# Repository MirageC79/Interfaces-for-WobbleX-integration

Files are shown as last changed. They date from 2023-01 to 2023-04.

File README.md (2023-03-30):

screen-gif
# Interfaces-for-WobbleX-integration

### Printers currently supported:
**Creality**
   - [Creality Ender 3](https://github.com/MirageC79/Interfaces-for-WobbleX-integration/tree/main/Creality/Ender3)

**RatRig**
   - [V-Core 3.1](https://github.com/MirageC79/Interfaces-for-WobbleX-integration/blob/main/RatRig/VCore3.1)  
   - V-Minion ........ *coming soon...*  

**Voron**
   - [Trident](https://github.com/MirageC79/Interfaces-for-WobbleX-integration/tree/main/Voron/Trident)  
   - V0 ............... *rear panel impacted, investigating feasibility and demand*  
<details><summary> Coming Soon: </summary>
<p>  

**VzBoT**
   - VZ235 ........... Currently not possible, clashing with RSCS ducting.
   - VZ330 ........... Currently not possible, clashing with RSCS ducting. 
</p>
</details>
<br>

**Mockups**
   - [Mockups for WobbleX custom installation](https://github.com/MirageC79/Interfaces-for-WobbleX-integration/tree/main/MockUp)
<br>

## What is WobbleX ?
The WobbleX isolators were born after spending a lot of efforts in creating a strong and reliable triple Z axis for self levelling with multi-axis printing provisions.
Because building a DIY 3D printer can induce a lot variability into the end result, we needed a way to limit the impact of:
- Components sources and origin
- Printed parts tolerances
- Assembly process
- User modifications 
- etc...

## How does it work?
This metallic version of the Wobble Rings from EvoMoto will compensate for screw wobbling AND nut tilting.  This 4 axis compensation ensures that the XY position of the bed will not be changed even if the screw is trying to.  It will also prevent the Z distance from being affected by a curved screw axis which would tilt the nut.

Each WobbleX Isolator is composed of an aluminum cross sandwiched between 4 Ball bearings and roller pins. The ball bearings will self center and retain themselves on the assembly using disc magnets.

One interface disc will allow the WobbleX to slide and pivot on the Screw Nut while the other interface disc will match the bed mount.  

## How can you integrate this on your printer?
In this repository you will find CADs and STLs that can be adapted to various 3D printers in order to benefit from the best Z wobble management system out there.

Buy WobbleX on Aliexpress Mellow 3D Official Store: https://s.click.aliexpress.com/e/_DDdeMyP

Preview of HevORT ZR2.6 Z axis integrating WS12 WobbleX:
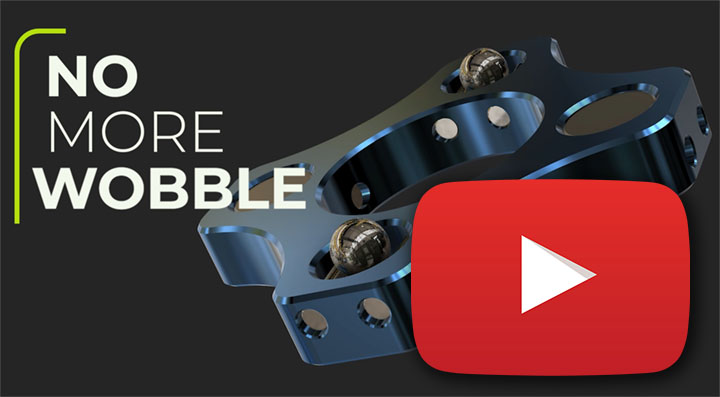
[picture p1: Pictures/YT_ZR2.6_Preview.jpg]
Video (https://www.youtube.com/watch?v=mLhklORNFBQ)


## Credits:
- EvoMoto for the awesome Idea
- Mellow 3D for materializing this idea
- HevORT Community for the support

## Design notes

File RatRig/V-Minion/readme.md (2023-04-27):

An Idea for the RatRig V-Minion based on the WobbleX concept. 

Improvement is in progress but it works pretty well so far.

It is not possible to order the WobbleX WS8 at my place so I designed something similar.

Additional to the printed parts I used:
* 16 pcs. steel pins 3x10 mm
* 4 pcs. 4 mm steel balls
* 8 pcs. 3x6 mm neodym magnets
* 2 pcs. M3x12 screws and nuts
* 1 pc. M3x6x5 threaded insert
* 1 pc. M3x10 screw

If you have the WobbleX WS8 you need less.

I printed everything in PLA with the steel pin side on the bed and 1mm brim. A pause has to be added in the slicer to insert the magnets.

At the V-Minion the lead screw should be aligned well with the coupler first, than replace the coupler with the WobbleX assembly.

WobbleXII_V-Minion

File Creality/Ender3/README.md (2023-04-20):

# Creality Ender 3

These parts will allow installation of WobbleX Isolators WS8 on Ender 3.  
## WARNING 
* Following user feedback, this system is not recommended for Dual Z cartesian printers.  The WobbleX require a certain amount of weight to keep them together.  A Dual Z installation would divide the XZ gantry weight.
* It is recommended that you use a T-Nut with limited amount of wear to avoid system twisting. Longer T-Nut with more threads is prefered.
* It is recommended that you use use a PTFE based lubricant or other friction reduction lubricants on you leadscrew.  

Notes:
* - I do not own a Creality Ender 3, these parts have not been physically validated.  See the [Feedback](/Creality/Ender3/README.md) section.
* - This mod will require that you relocate the stock Extruder.  Either go Direct Drive or create a bracket that will offset the extruder to make room for the WobbleX
* - Special care might be required to avoid nozzle bumping into blobs.  This might throw gantry up and separate the wobbleX.

## BOM
Bill of Material required to accomplish this modification:
|  Qty | Description | Link  |
|  :---:  |---|---|
|  1 | WobbleX WS8 kit for 8mm lead screw from Mellow 3D<br>Kit Includes:<br>  Qty8 - 3mm diam X 8mm longs pins<br>  Qty4 - 4mm ball screws<br>  Qty1 - WobbleX Assembly (Magnets and pins loaded)  | https://s.click.aliexpress.com/e/_DFcwPoH |
|  1 | 8mm T-Nut Adapter Lower Disc | [WobbleX_TR8_Adapter body.stl](https://github.com/MirageC79/Interfaces-for-WobbleX-integration/blob/main//Creality/Ender3/WobbleX_TR8_Adapter%20Body.stl)|
|  1 | Z carriage adapter | [ZCarriage_WS8.stl](https://github.com/MirageC79/Interfaces-for-WobbleX-integration/blob/main/Creality/Ender3/ZCarriage_WS8.stl)
|  1 | Top bearing mount (mandatory) | [TopBearingSupport_608.stl](https://github.com/MirageC79/Interfaces-for-WobbleX-integration/blob/main/Creality/Ender3/TopBearingSupport_608.stl)
|  1 | 608 Bearing |  AliExpress, Amazon, etc...
|  2 | M5X12 Button Head screws (for top bearing mount) | AliExpress, Amazon, etc...
|  5 | M3X8 Screws (3 for Z carriage Adapter +2 for lower disc) | AliExpress, Amazon, etc...
|  2 | 2020 M5 TNuts (for top bearing mount) | AliExpress, Amazon, etc...

## STEP files:  
[GitHub Directory](https://github.com/MirageC79/Interfaces-for-WobbleX-integration/tree/main/Creality/Ender3)
<br> 
<br>

## Feedback
I hope you enjoy this modification as much as I do.  As I dont have have an Ender 3 myself, I did not validate this installation physically. 
May you have any issue with the installation please [log an issue.](https://github.com/MirageC79/Interfaces-for-WobbleX-integration/issues)

Happy Printing :smiley:

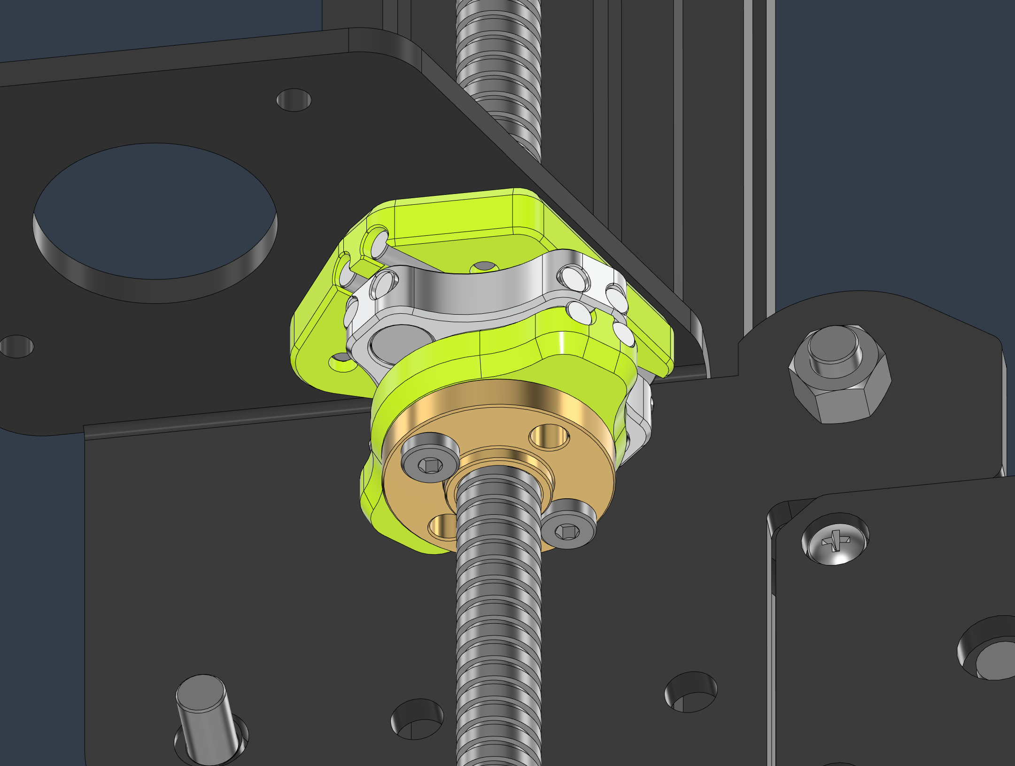
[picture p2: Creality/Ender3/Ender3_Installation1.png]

<br>
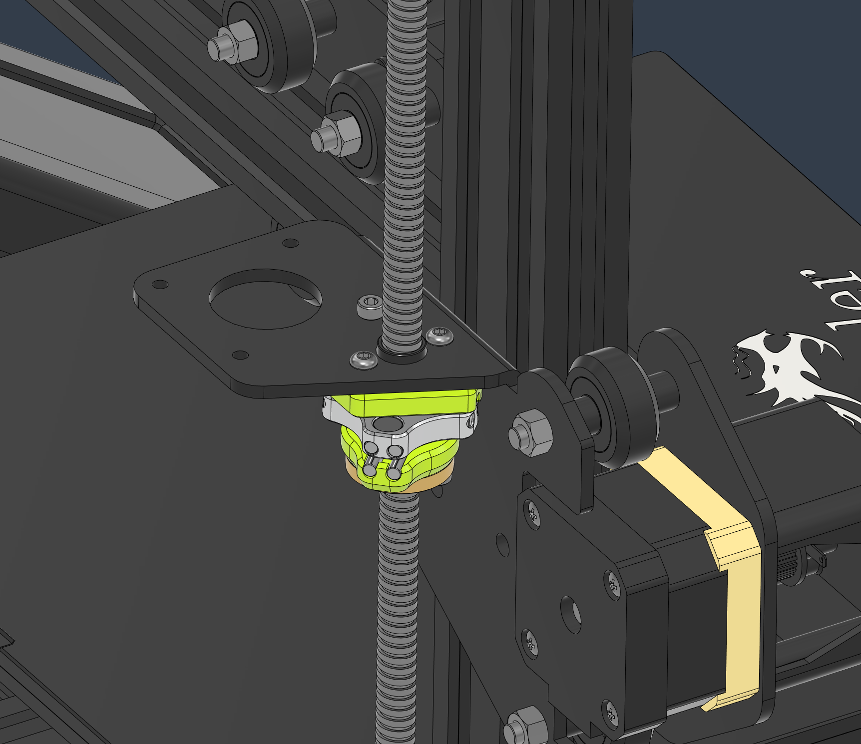
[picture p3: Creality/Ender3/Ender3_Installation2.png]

<br>
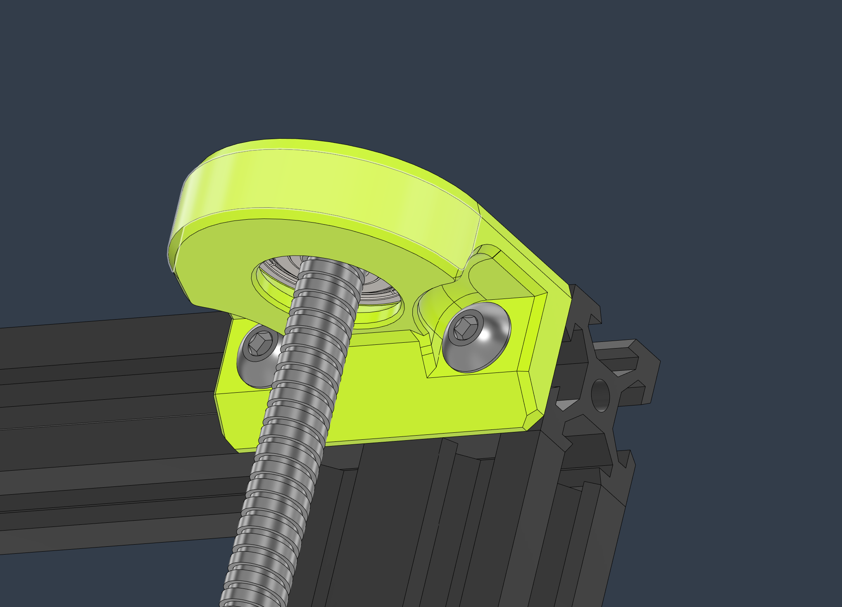
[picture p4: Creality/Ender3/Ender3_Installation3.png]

<br>
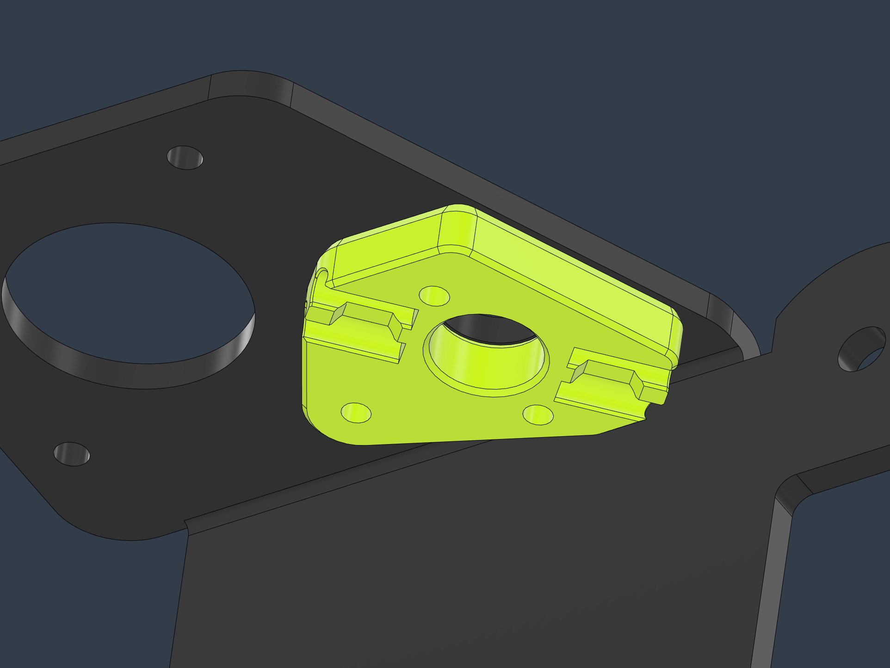
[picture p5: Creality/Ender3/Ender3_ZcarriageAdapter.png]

<br>

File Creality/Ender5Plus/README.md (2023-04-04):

Documentation is in work...

Creality Ender 5 Plus

Designed to reuse original hardware

Lead Screw support (TopBearingSupport_608.stl) is obtained from
https://www.thingiverse.com/thing:4808568
By mejico
https://www.thingiverse.com/mejico/designs

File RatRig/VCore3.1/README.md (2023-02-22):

# RatRig V-Core 3.1

These parts will allow installation of WobbleX Isolators WS8 on RatRig V-Core 3.1.  

Notes:
* - I do not own a RatRig V-Core, these parts have not been physically validated.  See the [Feedback](/RatRig/VCore3.1/README.md) section.

## BOM
Bill of Material required to accomplish this modification:
|  Qty | Description | Link  |
|  :---:  |---|---|
|  3 | WobbleX WS8 kit for 8mm lead screw from Mellow 3D | https://s.click.aliexpress.com/e/_DFcwPoH |
|  3 | 8mm T-Nut Adapter Lower Disc | [WobbleX_TR8_Adapter v6.stl](https://github.com/MirageC79/Interfaces-for-WobbleX-integration/blob/main/RatRig/VCore3.1/WobbleX_TR8_Adapter%20Body.stl)|
|  1 | Bed Arm left | [BedArmLeft_3.1_WS8.stl](https://github.com/MirageC79/Interfaces-for-WobbleX-integration/blob/main/RatRig/VCore3.1/BedArmLeft_3.1_WS8.stl)|
|  1 | Bed Arm Right | [BedArmRight_3.1_WS8.stl](https://github.com/MirageC79/Interfaces-for-WobbleX-integration/blob/main/RatRig/VCore3.1/BedArmRight_3.1_WS8.stl)|
|  1 | Bed Arm Back | [BedArmBack_3.1_WS8.stl](https://github.com/MirageC79/Interfaces-for-WobbleX-integration/blob/main/RatRig/VCore3.1/BedArmBack_3.1_WS8.stl)|

## STEP files:  
[GitHub Directory](https://github.com/MirageC79/Interfaces-for-WobbleX-integration/tree/main/RatRig/VCore3.1)
<br> 
<br>

## Feedback
I hope you enjoy this modification as much as I do.  As I dont have have a Trident myself, I did not validate this installation physically. 
May you have any issue with the installation please [log an issue.](https://github.com/MirageC79/Interfaces-for-WobbleX-integration/issues)

Happy Printing :smiley:
<br><br>

## Gallery
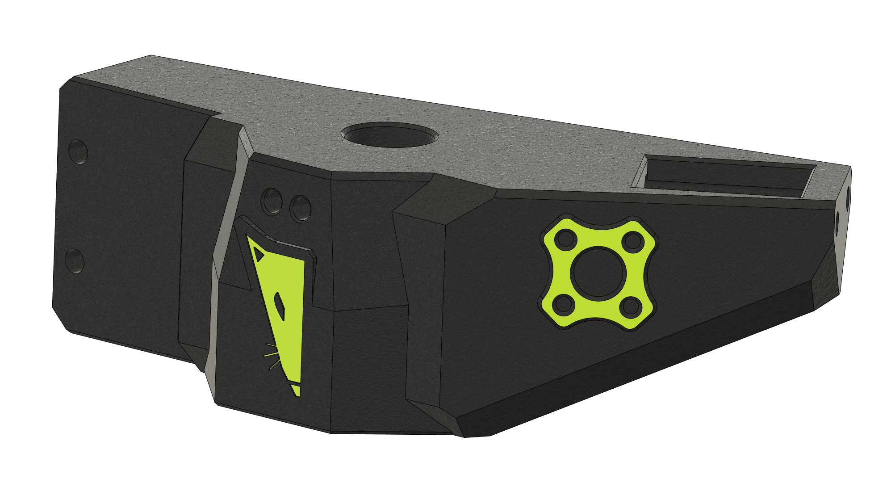
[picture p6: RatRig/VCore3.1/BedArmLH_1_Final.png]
 
<br>  
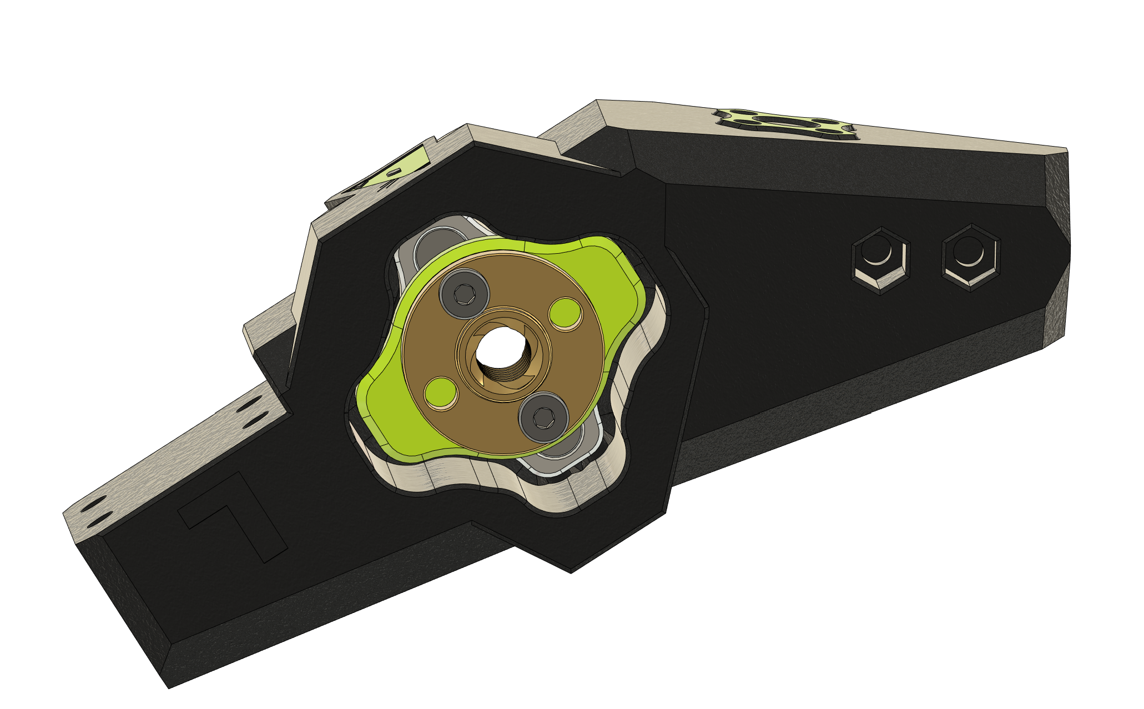
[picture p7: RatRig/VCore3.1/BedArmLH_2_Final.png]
 
<br>
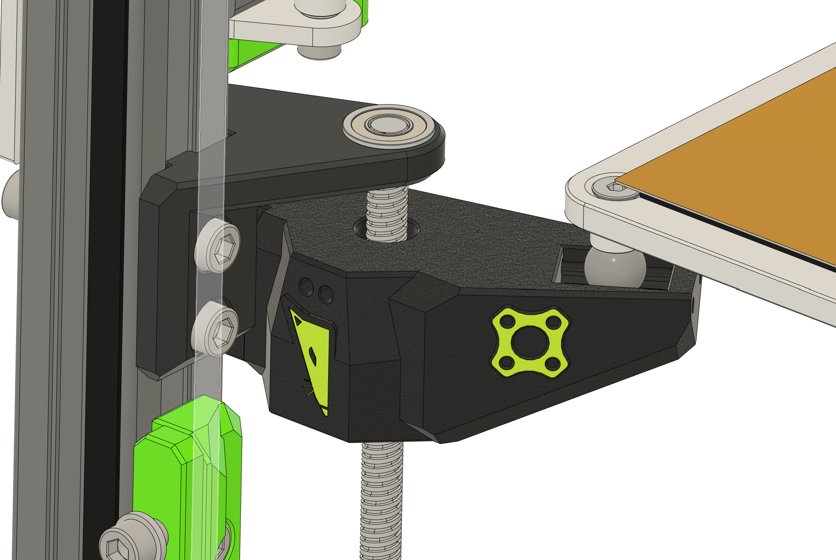
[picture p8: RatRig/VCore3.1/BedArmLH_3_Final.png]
 
<br>  
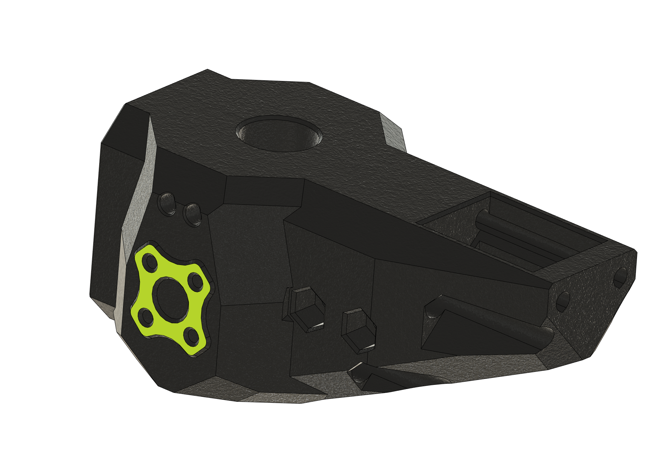
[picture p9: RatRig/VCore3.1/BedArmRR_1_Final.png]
 
<br>  
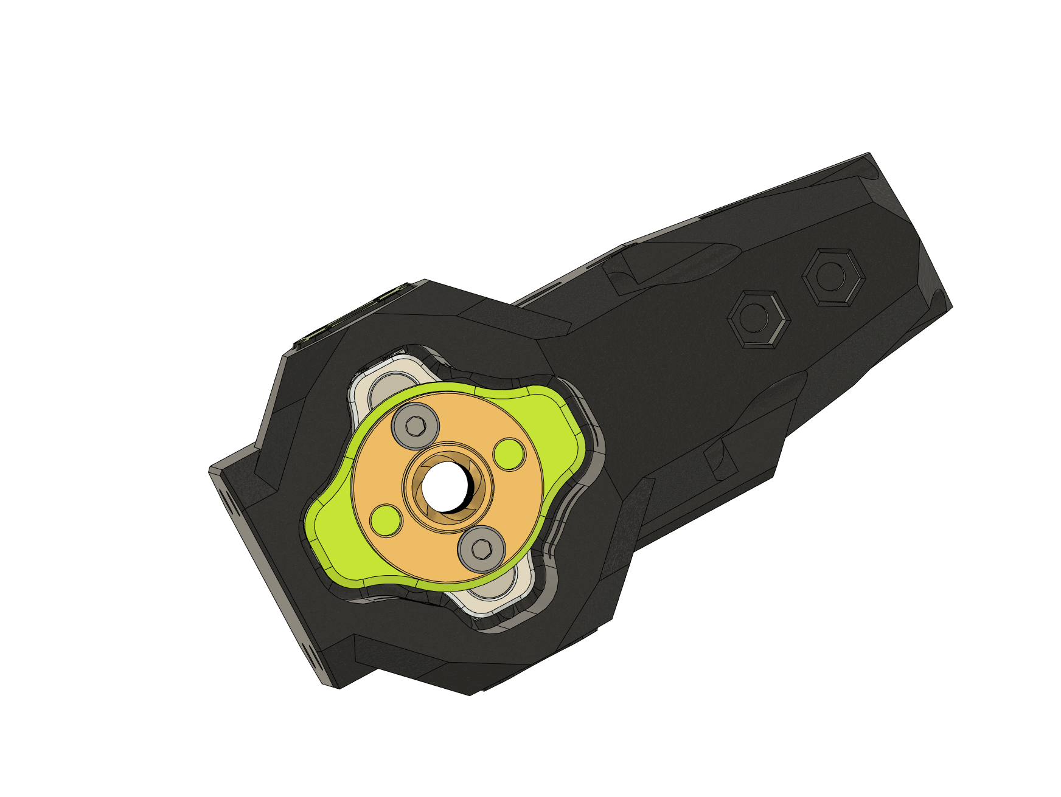
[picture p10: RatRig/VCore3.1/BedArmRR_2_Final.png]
 
<br>
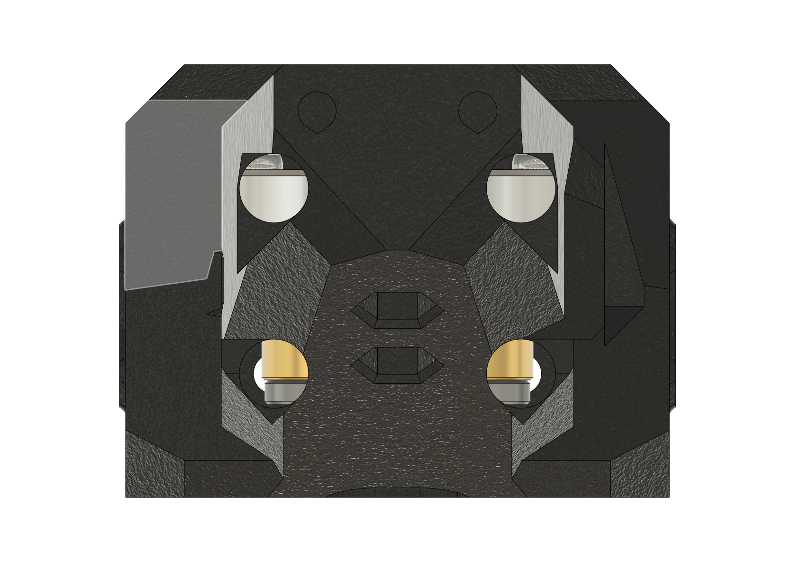
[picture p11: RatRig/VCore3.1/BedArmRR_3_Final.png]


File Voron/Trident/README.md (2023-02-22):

# Voron Trident

These parts will allow installation of WobbleX Isolators WS8 on Voron Trident.  

Notes:
* 1 - The maximum Z travel distance will be reduced by 17mm with this mod.
* 2 - I do not own a Voron Trident, these parts have not been physically validate.  See the [Feedback](/Voron/Trident/README.md) section.

## BOM
Bill of Material required to accomplish this modification:
|  Qty | Description | Link  |
|  :---:  |---|---|
|  3 | WobbleX WS8 kit for 8mm lead screw from Mellow 3D | https://s.click.aliexpress.com/e/_DFcwPoH |
|  3 | 8mm T-Nut Adapter Lower Disc | [WobbleX_TR8_Adapter v6.stl](https://github.com/MirageC79/Interfaces-for-WobbleX-integration/blob/main/Voron/Trident/WobbleX_TR8_Adapter%20Body.stl)|
|  1 | Z Carriage lower plate front left | [ZCarriageLeft_Plate_WS8.stl](https://github.com/MirageC79/Interfaces-for-WobbleX-integration/blob/main/Voron/Trident/ZCarriageLeft_Plate_WS8.stl)|
|  1 | Z Carriage lower plate front Right | [ZCarriageRight_Plate_WS8.stl](https://github.com/MirageC79/Interfaces-for-WobbleX-integration/blob/main/Voron/Trident/ZCarriageRight_Plate_WS8.stl)|
|  1* | *Option #1 - Rear Z Carriage modified for WS8 ( Two holes) | [ZCarriageRear_2holes_WS8.stl](https://github.com/MirageC79/Interfaces-for-WobbleX-integration/blob/main/Voron/Trident/ZCarriageRear_2holes_WS8.stl)|
|  1* | *Option #2 - Rear Z Carriage modified for WS8 ( Three holes)| [ZCarriageRear_3holes_WS8.stl](https://github.com/MirageC79/Interfaces-for-WobbleX-integration/blob/main/Voron/Trident/ZCarriageRear_3holes_WS8.stl)| 

## STEP files:  
[GitHub Directory](https://github.com/MirageC79/Interfaces-for-WobbleX-integration/blob/main/Voron/Trident/README.md)
<br> 
<br>

## Feedback
I hope you enjoy this modification as much as I do.  As I dont have have a Trident myself, I did not validate this installation physically. 
May you have any issue with the installation please [log an issue.](https://github.com/MirageC79/Interfaces-for-WobbleX-integration/issues)

Happy Printing :smiley:
<br><br>

## Gallery
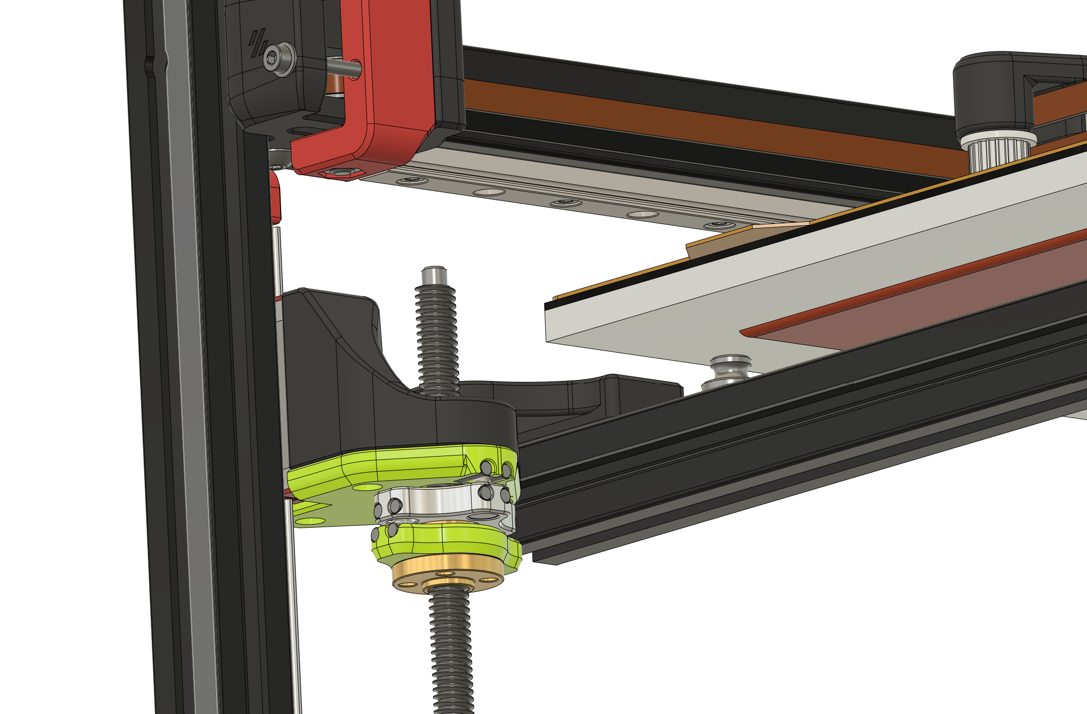
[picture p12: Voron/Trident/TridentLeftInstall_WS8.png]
 
<br>  
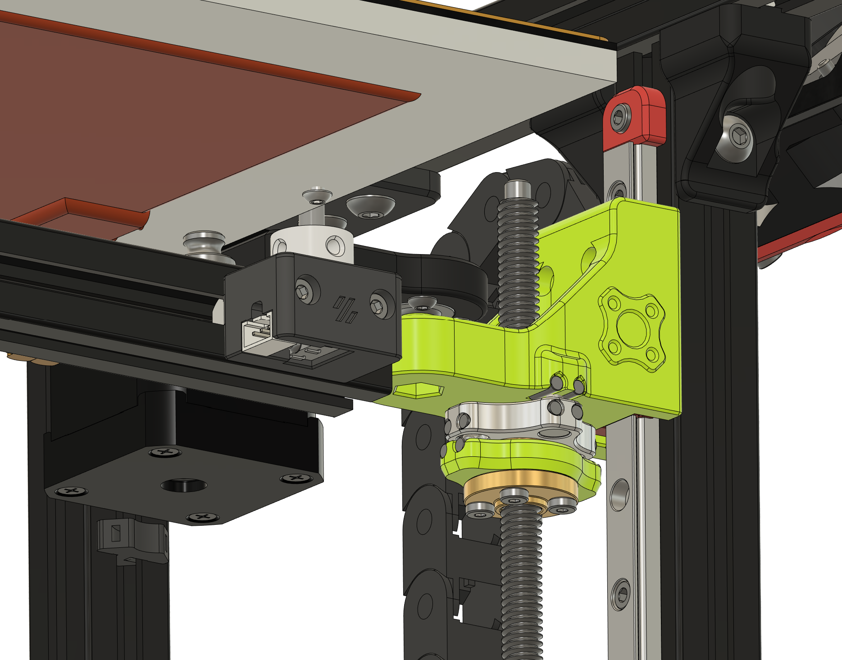
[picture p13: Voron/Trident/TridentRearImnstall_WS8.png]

<br>
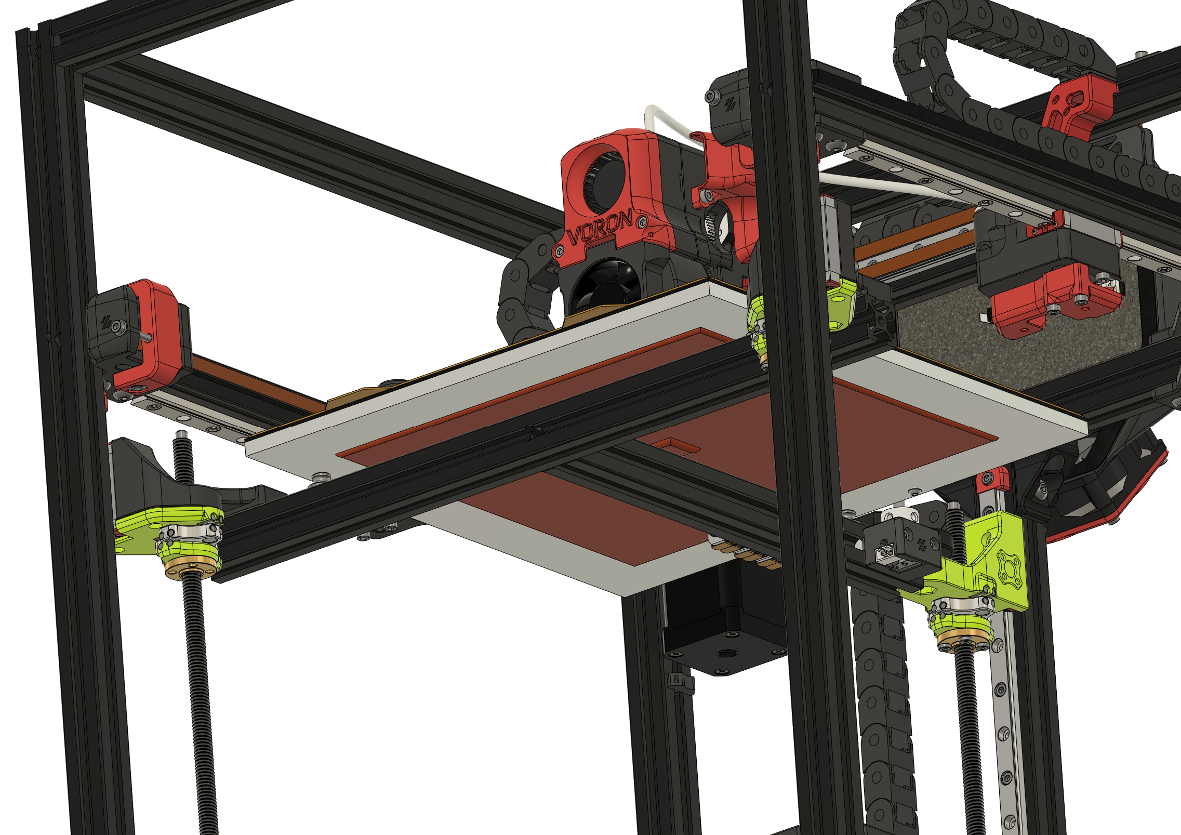
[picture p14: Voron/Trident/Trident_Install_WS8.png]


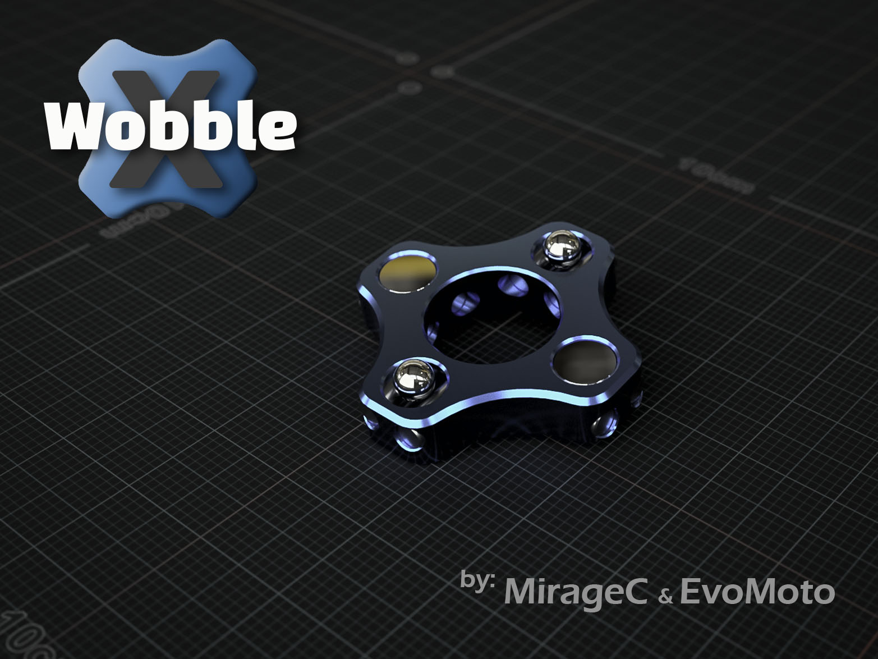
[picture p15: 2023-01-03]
Pictures/WobbleRingsMetalCenter_TR8 v10-Edit copy.jpg

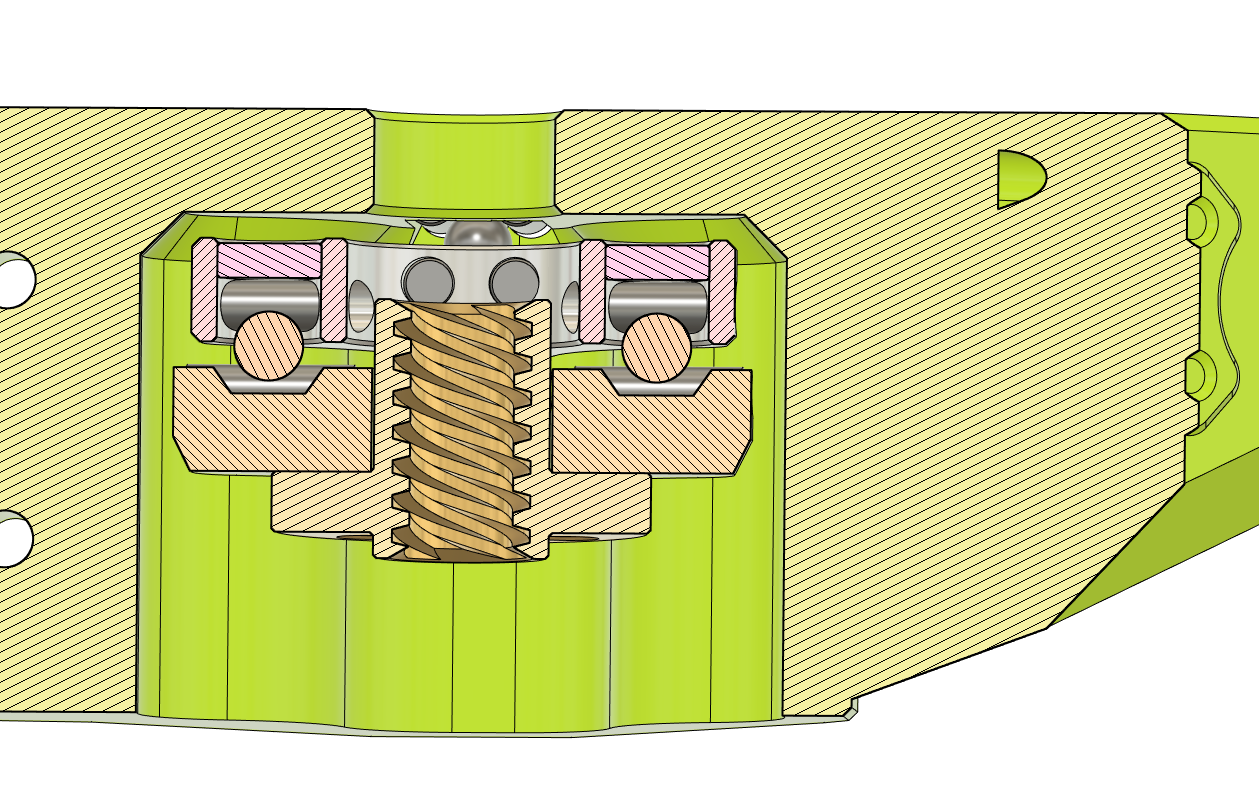
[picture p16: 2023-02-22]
RatRig/VCore3.1/Vcore_SectionView.png

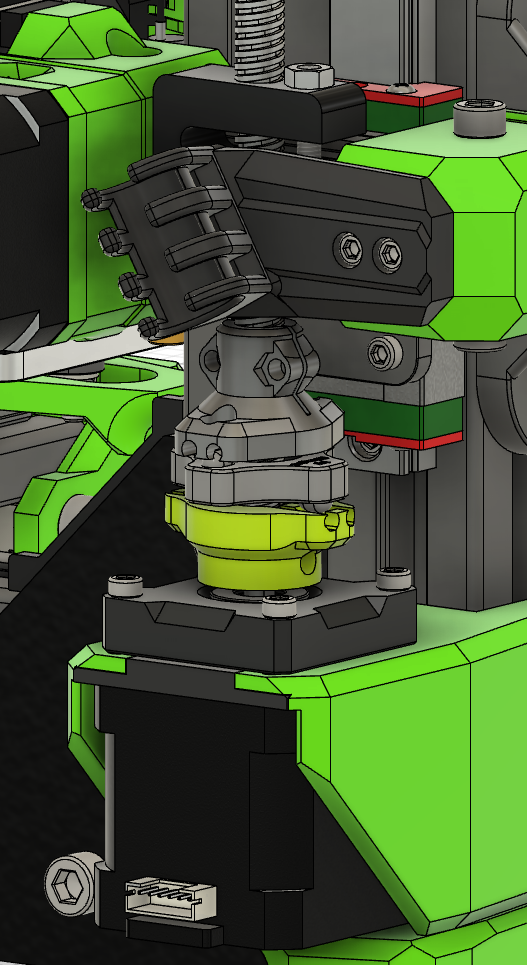
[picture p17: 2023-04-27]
RatRig/V-Minion/WobbleXII_V-Minion.png

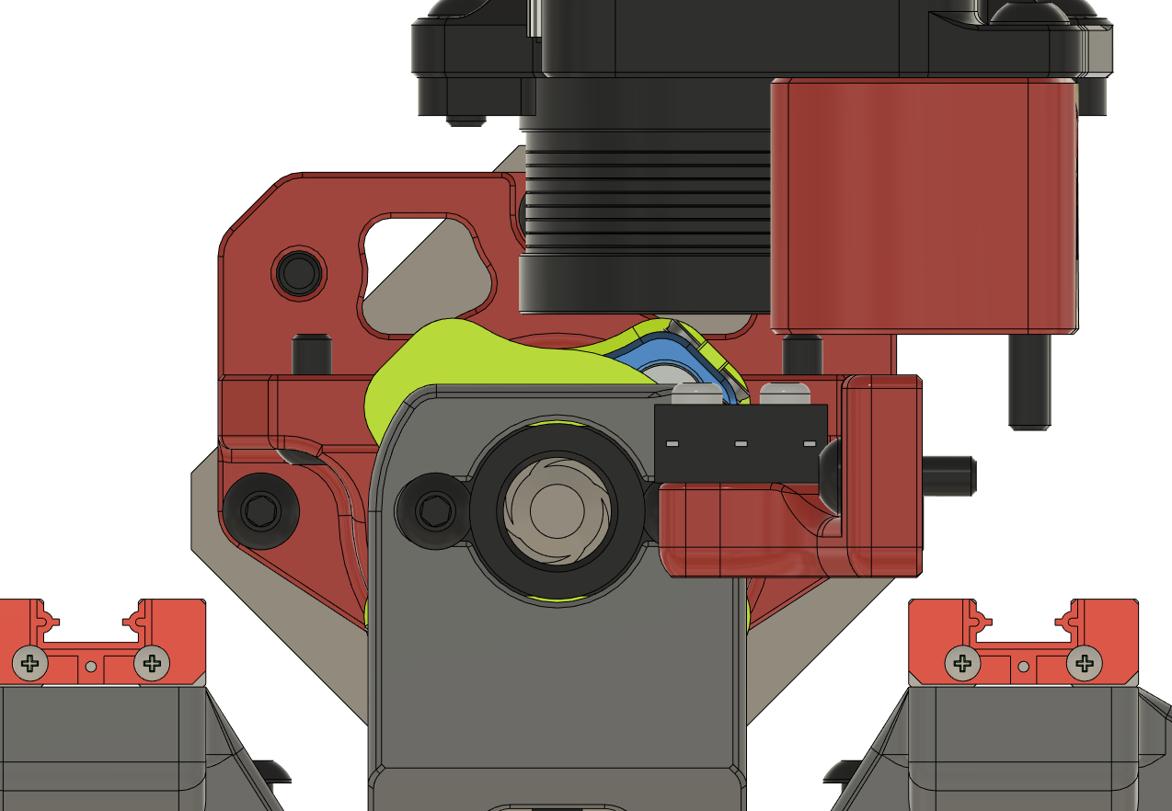
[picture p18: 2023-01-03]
Voron/V0.1/Voron_V0.1_WobbleX_T8_Clearance_45deg_Top.png

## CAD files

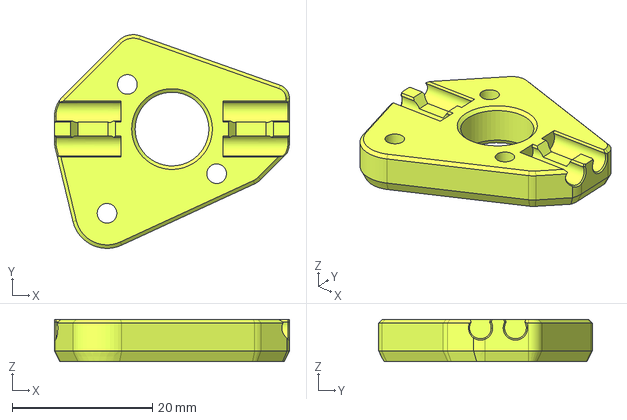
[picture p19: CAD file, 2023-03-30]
Creality/Ender3/ZCarriage_WS8.step
33.5 x 30.5 x 6.00 mm

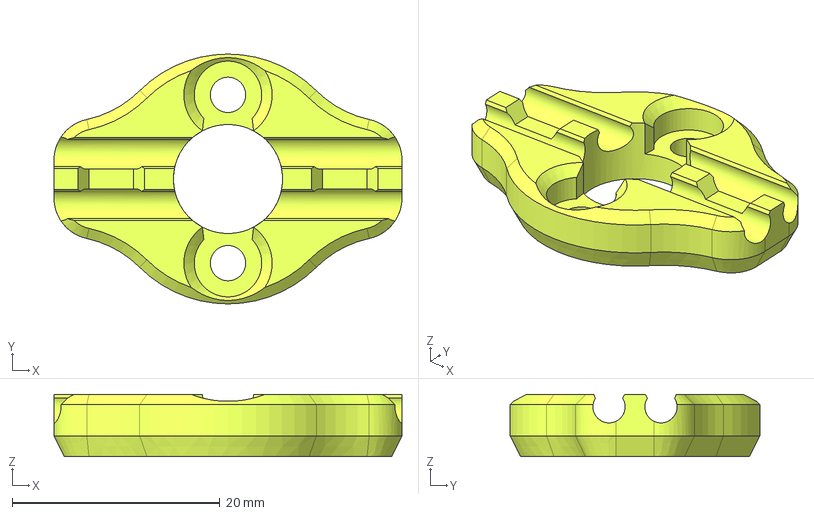
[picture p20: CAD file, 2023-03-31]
Creality/Ender5Plus/WobbleX_WS8_Ender5PlusAdapter.step
33.5 x 24.0 x 6.00 mm

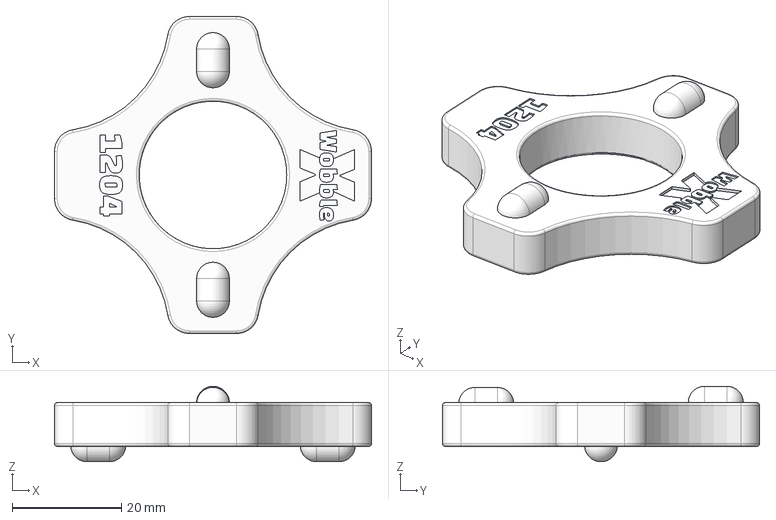
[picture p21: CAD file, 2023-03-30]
MockUp/WobbleX_WS12_MockUp.step
58.0 x 58.0 x 13.8 mm

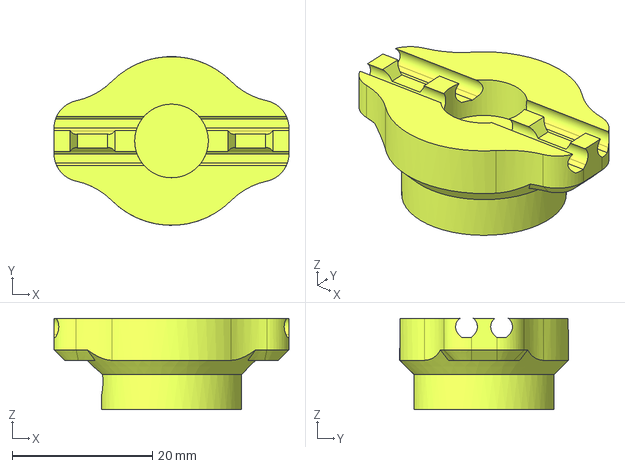
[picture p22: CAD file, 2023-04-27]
RatRig/V-Minion/WobbleXII_lower.step
33.5 x 24.0 x 13.0 mm

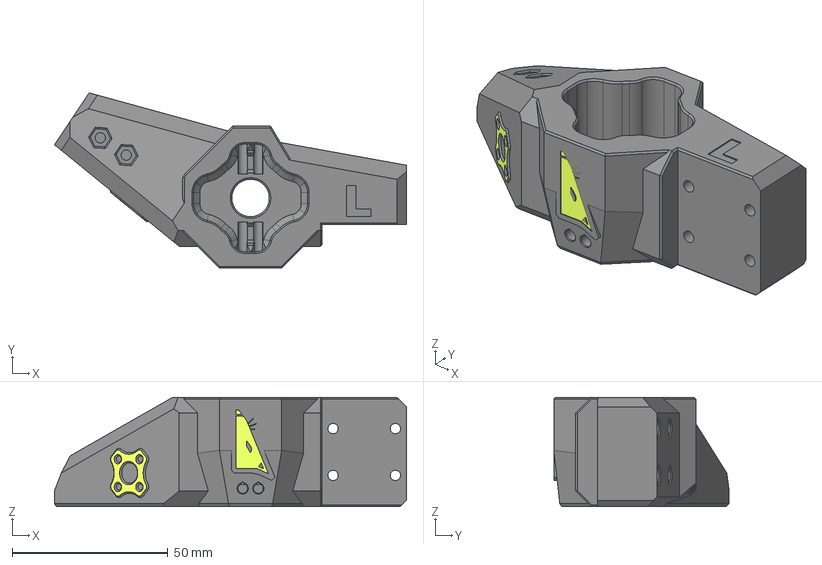
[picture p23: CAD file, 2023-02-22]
RatRig/VCore3.1/BedArmLeft_3.1_WS8.step
112.9 x 56.2 x 35.0 mm

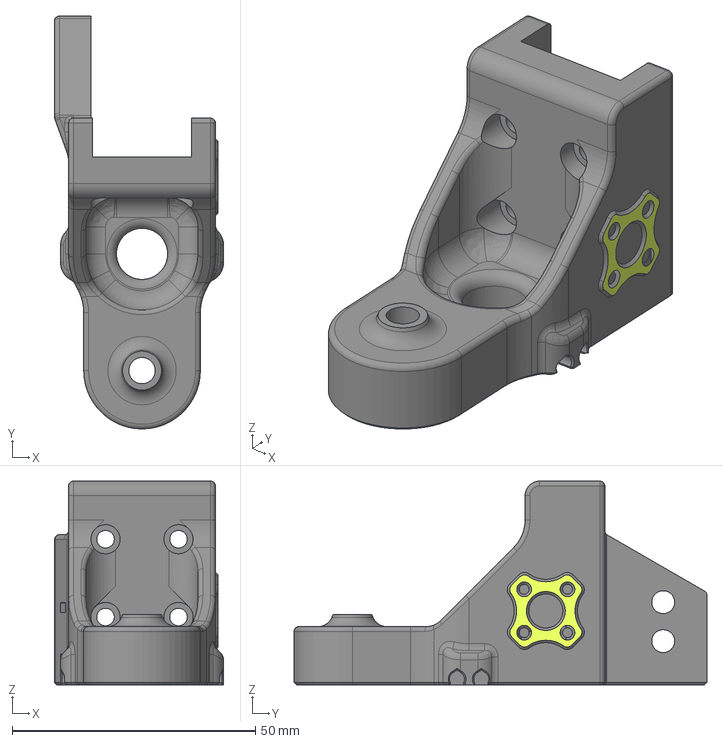
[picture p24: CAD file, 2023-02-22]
Voron/Trident/ZCarriageRear_2holes_WS8.step
34.8 x 84.9 x 41.9 mm

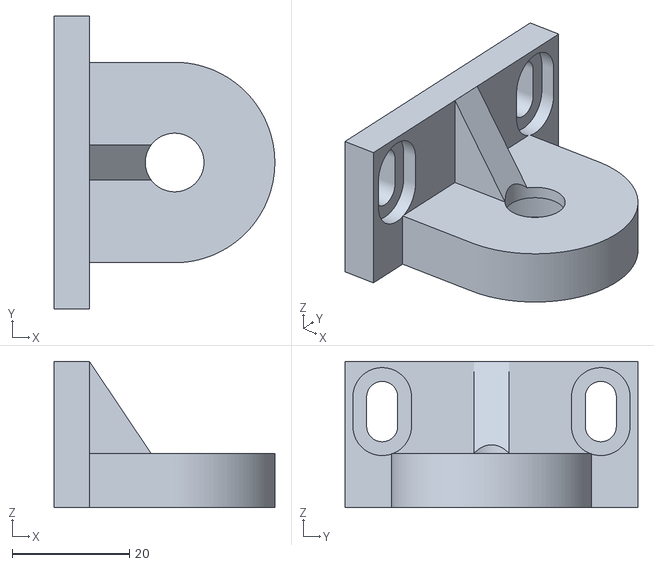
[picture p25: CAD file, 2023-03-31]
Creality/Ender5Plus/TopBearingSupport_608.stl
37.7 x 50.0 x 25.0

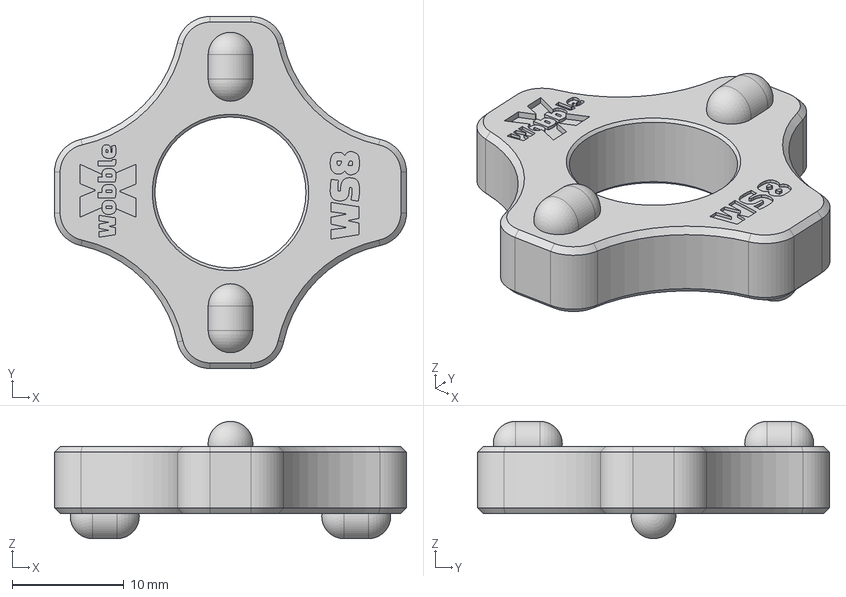
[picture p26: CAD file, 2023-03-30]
MockUp/WobbleX_WS8_MockUp.step
31.5 x 31.5 x 10.5 mm

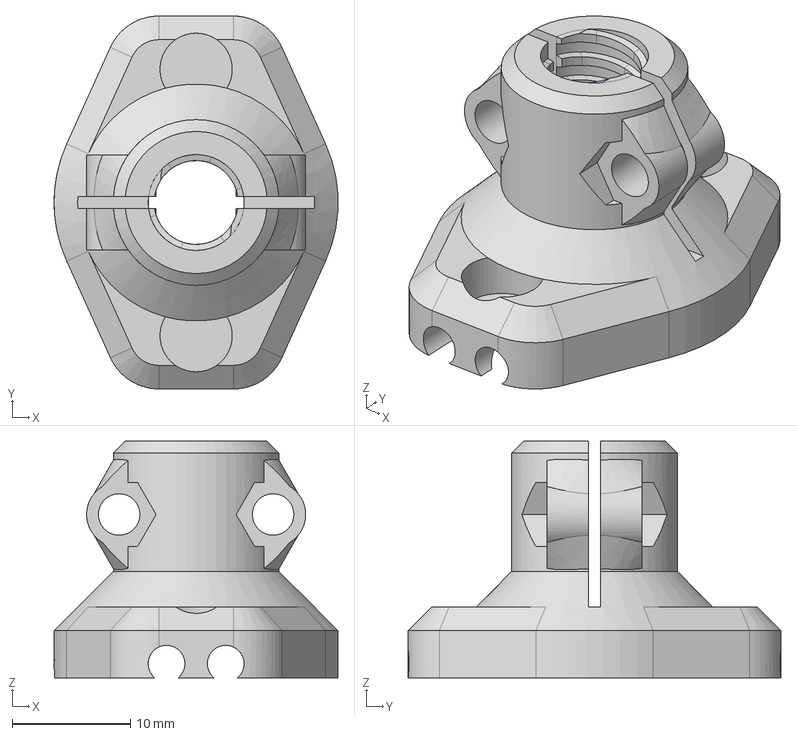
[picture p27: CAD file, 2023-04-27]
RatRig/V-Minion/WobbleXII_upper.step
24.0 x 31.5 x 20.0 mm

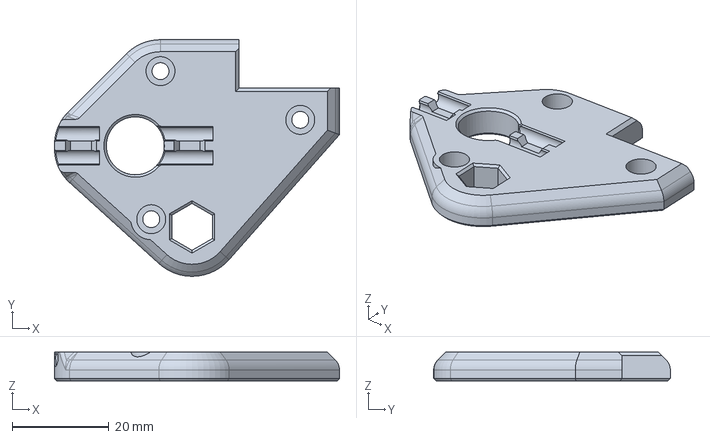
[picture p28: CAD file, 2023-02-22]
Voron/Trident/ZCarriageRight_Plate_WS8.step
59.1 x 49.0 x 6.00 mm

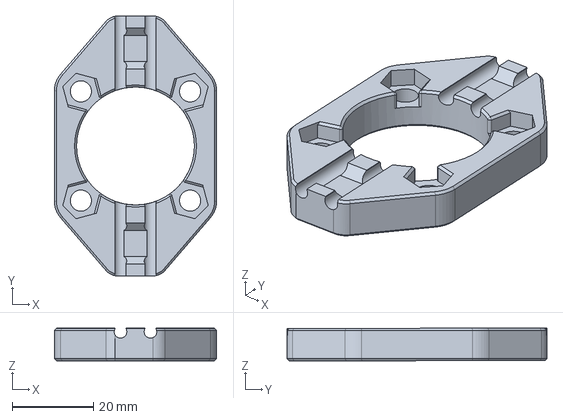
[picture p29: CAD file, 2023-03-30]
MockUp/WobbleX_WS16_PrintedAdapter.step
40.0 x 64.0 x 8.00 mm

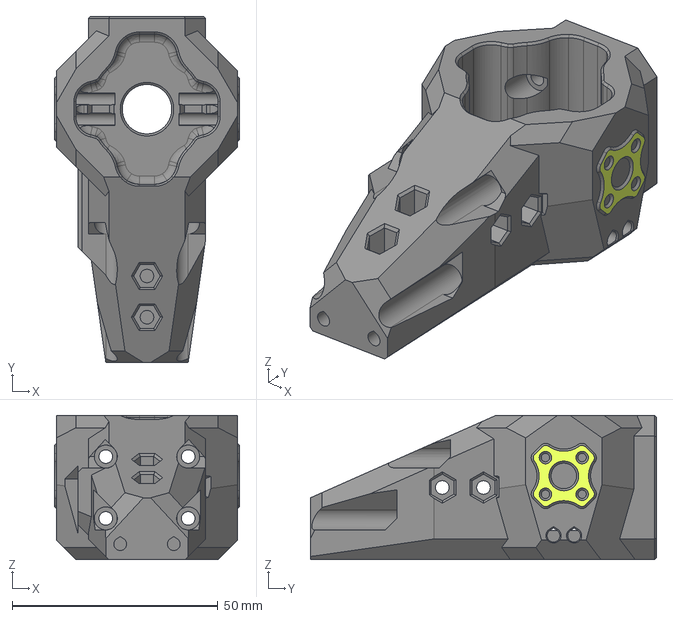
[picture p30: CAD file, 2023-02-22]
RatRig/VCore3.1/BedArmBack_3.1_WS8.step
45.0 x 84.0 x 35.0 mm

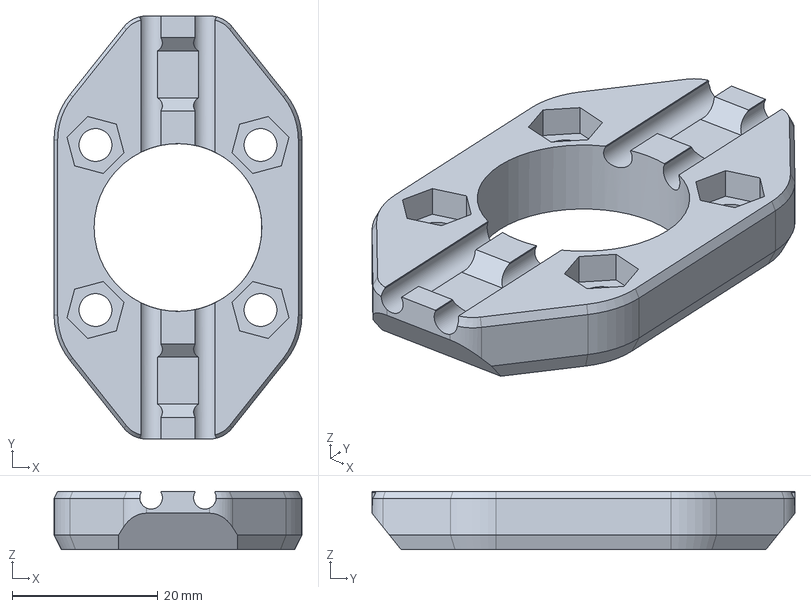
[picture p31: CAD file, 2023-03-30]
MockUp/WobbleX_WS12_PrintedAdapter.step
34.0 x 58.0 x 8.00 mm

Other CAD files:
Creality/Ender3/WobbleX_TR8_Adapter Body.step
RatRig/VCore3.1/BedArmRight_3.1_WS8.step
Voron/Trident/ZCarriageLeft_Plate_WS8.step
MockUp/WobbleX_WS8_PrintedAdapter.step
Voron/Trident/ZCarriageRear_3holes_WS8.step
Creality/Ender3/WobbleX_TR8_Adapter Body.stl
Creality/Ender3/ZCarriage_WS8.stl
Creality/Ender5Plus/WobbleX_WS8_Ender5PlusAdapter.stl
MockUp/WobbleX_WS16_MockUp.step
RatRig/V-Minion/WobbleXII_lower.stl
RatRig/VCore3.1/BedArmBack_3.1_WS8.stl
RatRig/VCore3.1/BedArmLeft_3.1_WS8.stl
RatRig/VCore3.1/BedArmRight_3.1_WS8.stl
Voron/Trident/ZCarriageLeft_Plate_WS8.stl
Voron/Trident/ZCarriageRear_2holes_WS8.stl
Voron/Trident/ZCarriageRear_3holes_WS8.stl
Voron/Trident/ZCarriageRight_Plate_WS8.stl

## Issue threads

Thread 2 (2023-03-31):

Print files of WobbleX

pasha4ur, 2023-03-31:
Hello.

You are not giving the community the files to make WobbleX yourself.

Can you give the community (whose idea you used in this product ) the self-printing files (step and stl) for WobbleX?

Or are you afraid that you won't make all the money in the world by selling a device you created based on a free and open idea from thingverse project?

Anyway, someone will design these files and put them in the public domain. Don't be greedy.

MirageC79, 2023-03-31:
1 - Credits were given to the original inventor from the start (who is part of this project by the way...)
2 - And CADs where published 3 month ago for a printable version here https://a360.co/40QC5G5

What are your motivations to go that hard on this? We are not making much.  And it is to fund other development and documentation activities that will benefit the public in the end.

GlowPon3, 2023-03-31:
I'm just thankful they are putting these together for us, they aren't even that expensive.  Besides, it's not that hard to model something similar yourself.  There's no need for such aggression.

MsnSazabi, 2023-04-02:
>

Mellow wants 108USD for shipping for 4pcs to me for some reason. This is why I'd make those myself. I'd better tip directly to you.

MirageC79, 2023-04-04:
> >
>
> Mellow wants 108USD for shipping for 4pcs to me for some reason. This is why I'd make those myself. I'd better tip directly to you.

Each country has fees and taxes that need to be added to the shipping price.  Mellow is only applying what your government is charging them to get stuff in your country.

Here is how much shipping is to Canada:

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

MirageC79, 2023-04-04:
As mentioned in the video, this is the design that was used as the source idea: https://www.thingiverse.com/thing:4781610
WS8 should not be printed, they are too small and will delaminate.  WS12 printable version are posted up here.

Not sure what you mean by "Corrected" open source idea?  Are there issues with the original design?

pasha4ur, 2023-04-04:
> WS8 should not be printed, they are too small and will delaminate.

Or will not delaminate.

pasha4ur, 2023-04-09:
> As mentioned in the video, this is the design that was used as the source idea: https://www.thingiverse.com/thing:4781610 WS8 should not be printed, they are too small and will delaminate. WS12 printable version are posted up here.
>
> Not sure what you mean by "Corrected" open source idea? Are there issues with the original design?

https://www.thingiverse.com/thing:4781610

HevORT Wobble Rings for FSU1204 ball screws by[EvoMotors](https://www.thingiverse.com/EvoMotors) is licensed under the [Creative Commons - Attribution - Non-Commercial](https://creativecommons.org/licenses/by-nc/4.0/) license.

Non-Commercial

Closed 2023-04-04.

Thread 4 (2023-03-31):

RatRig V-Minion

TekuSP, 2023-03-31:
Hey,

When we can expect V-Minion version? I have constant fight with wobbling.

Thank you

MirageC79, 2023-03-31:
I hope the community chips in with these designs, I will try to address as many printers as possible, but the list is growing FAST!
Meanwhile, have you seen this video: https://youtu.be/c6JmCdovE0U
Many sources of artifact may seem to be Z wobble, but they end up being something else.

junk495, 2023-04-07:
Hello, I did it that way: https://github.com/junk495/WobbleXII-V-Minion/tree/main/RatRig/V-Minion
Works pretty good so far.
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

junk495, 2023-05-17:
Thank you for the feedback and the pictures, makes me happy to see that.

TekuSP, 2023-05-26:
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

I have tested it @memphisdj and only result I got was Wobble X flying off while trying to do just HOME Z. Can you provide better pictures? What extruder/hotend combo you have? Because my gantry feels too light for this. Maybe I am doing something wrong.

MirageC79, 2023-05-26:
Oh! wow!  This is awesome!
@junk495  what a clever idea!  I love how you installed the wobbleX right at the motor coupling!  This Idea should simplify the installation for many printers!

@memphisdj Glad that you like it!  Great print 👍🏼

ZeyHex, 2023-07-02:
I thought it would be cool to use the suggested coupler adapter and just make a split coupler. It turned out like this.
https://www.printables.com/model/518585-ws8-coupling

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

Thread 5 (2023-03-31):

Creality 3 / PRO

Almazick, 2023-03-31:
I'm just a little bit confused.  The model in Creality folder shows 2 parts but missing dimensions for pins and ball sizes.  Personally I'd like to buy the whole kit from https://www.aliexpress.us/item/3256804040834604.html
Even if buy your part it won't work because it's missing the other 2 parts.  I can't make these parts because they are missing build information for pins and balls.  Can you elaborate?

MirageC79, 2023-04-04:
Hi, The WS8 kit comes with
- One cross pre assembled with qty4 magnets and qty8 3mm pins
- Qty 4 Ball bearings of 4mm diameter (I have asked Mellow to add two spares)
- Qty 8 additional 3mm diameter X 8mm long pins to be inserted in the printed parts.

The BOM and details for Ender3 has been updated.

I am closing the ticket with this comment, but do not hesitate to let me know if you need more info.
Regards,

Closed 2023-04-04.

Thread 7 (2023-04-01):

Ender3 issues

leecuk, 2023-04-01:
Hi, great project,

I believe the WobbleX_TR8_Adapter Body might have a small issue.

Design has a 16mm screw mount PCD, the brass nut actually has an 18mm PCD.

Additionally, the existing nut has threaded holes which would require the screw to be from the top, how much clearance on top is required for the WobbleX movement?

Thanks
Lee

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

MirageC79, 2023-04-04:
Oh!  sweet! thanks for the update.  I'll revise the design.

julian-margara, 2023-04-14:
Hi there,

I modified the PCD to 18mm, I'm not a design expert by any means but maybe my change will help to someone else.

I can't upload the file here but here is the OnShape document from where it's possible to export to any format (stl, step, etc).
https://cad.onshape.com/documents/cc9a77c7250780a055705ba5/w/e54ded23702a3f2bf6409cc8/e/cab1ab567e6af58cdebe1ea9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

I'll update my feedback here after testing it (waiting my kit from AliExpress!)

Best

leecuk, 2023-04-14:
Might need a recess for screw to sit in, the nut is tapped and requires the screw to be from above. I’m not sure how much clearance is needed. Also waiting on my kit.

julian-margara, 2023-04-14:
@leecuk why don't put the screw from below? (honest question)

Look how it looks with the 18mm PCD and using the screws (stock ones) from below:
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

leecuk, 2023-04-14:
Unless you drill out the thread in the nut, once the screw hits the bottom of the nut thread, it won’t pull the two pieces together. I believe it is sometimes called screw bridging or jacking.

I also can’t say I’m a fan of tapping directly into the plastic, but a possibly a threaded insert might make it better.

leecuk, 2023-04-29:
@julian-margara
My WobbleX arrived today, I'm not sure if I ended up purchasing a clone, but the included rollers were a little shorter than expected.

The bottom mount fouls the carriage bracket on the ender3, so I've chopped the corner off.

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

I used threaded inserts for the top adapter.

I've uploaded step files to https://github.com/leecuk/WobbleX-Ender3 if anyone wants them.

nevermor113, 2023-05-17:
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

can you send me the middle part file? I didn't see them post it online

ESOCHI, 2023-11-12:
> Oh! sweet! thanks for the update. I'll revise the design.

Just fyi, mine was still 16 when I downloaded the Ender3 files.

ESOCHI, 2023-11-12:
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

How did you get the stepper back on? That 3rd bolt for the top plate conflicts with one of the 4 mounting points for the stepper.

I flipped the top mount 180 and that gave me more room.

I'm just offsetting the stepper by 1cm so I've cut the entire middle circle section out, and I'm re-drilling 2 of the holes. I'll then need to extend the bracket to add the other 2 holes which I may do by drilling an aluminum business card out to fit the stepper, then bolt that to the bracket or something.

[Here's a google album with some pics of everything.](https://photos.app.goo.gl/tgNgBSQznW8CyqgE9)

leecuk, 2023-11-13:
I’ve completely shifted the extruder. I’m running a e3d titan extruder, so made an adapter plate that bolts into the original mount. You can see it in my photos.

leecuk, 2024-03-23:
So, it's been just under a year since I installed the WobbleX on the ender, got to say the results are fantastic, so thanks to everyone that put it together.

In terms of the ender3 v2 files, the ones on this repo still aren't currently compatible, but I've got them over at https://github.com/leecuk/WobbleX-Ender3 if anyone want them.

Closed 2024-03-23.

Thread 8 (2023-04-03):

Voron Trident MGN12H rear Z

Exerqtor, 2023-04-03:
I've made a MGN12H version of the rear Z carriage for those who want that (both 2 & 3 hole).

I'll just submit the CAD here, forking and creating a pull request for this is too much work lmao.

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
[WobbleX-MGN12H_rear_Z.zip](https://github.com/MirageC79/Interfaces-for-WobbleX-integration/files/11135149/WobbleX-MGN12H_rear_Z.zip)

MirageC79, 2023-04-04:
Awesome Thank you!  I'll leave the ticket opened as a reminder to me to incorporate this tomorrow.

MarkusNiewoehner, 2024-02-07:
**Awesome Thank you! I'll leave the ticket opened as a reminder to me to incorporate this tomorrow.**

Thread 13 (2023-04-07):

Print files of WobbleX #2

pasha4ur, 2023-04-07:
Hello

You closed topic and didn't answer:  https://github.com/MirageC79/Interfaces-for-WobbleX-integration/issues/2

Will you give us files for selfprinting (WS8 and WS12 too) or  you are so greedy that you will sell remade free solution?

3d print community wants to know how low you can fell.

pasha4ur, 2023-04-09:
Source of idea for your parts as you said: https://www.thingiverse.com/thing:4781610

HevORT Wobble Rings for FSU1204 ball screws by[EvoMotors](https://www.thingiverse.com/EvoMotors)is licensed under the[Creative Commons - Attribution - **Non-Commercial**](https://creativecommons.org/licenses/by-nc/4.0/) license. https://creativecommons.org/licenses/by-nc/4.0/

pasha4ur, 2023-05-24:
Print version https://www.printables.com/model/439423-wobble-biscuit/comments

Greedy Mirage will not share

MirageC79, 2023-05-24:
Yeah... I am soooo greedy!  all of the ideas me and my team have put forward over the years... Yet this simple side project is what you use to label me as greedy...

Can't see the forest for the trees...

Closed 2023-05-24.

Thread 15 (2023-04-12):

Trident parts

thiagolocatelli, 2023-04-12:
Just received my 3 WobbleX WS8 to install on the Trident. I have a Voron 2.4, very well tuned (printed a lot of Voron Kits with it) and printed all the parts for WobbleX on my 2.4. Having that said, two issues:

The pins I received have length of ~10mm and thickness of ~2.95mm (0.03 more/less - some are even 2.92mm).

1) None of the pins that came with the WS8 stay on any of the slots in any of the printed parts. They slide right out with just gravity. Shouldn't they be a snug fit? It would be difficult to assemble all 3 Z axis having to worry about pins falling off. I could glue them but also believe it should be a snug fit so I can apply so force while pushing them in.

2) The rear Z carriage mount with integrated slots for the pins. When the pins are in place, the little metal ball does not touch the pins, it rests on the printed part since the rear Z mount does not have the recess like other parts have.

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

If you can get me updated STLs I can go ahead and print them again.

MirageC79, 2023-04-12:
Oh wow!  sorry to hear that.  I assume this is a kit from Mellow3D and not one of the many clones that are appearing on AliExpress lately?

I'll measure the pins I have here in my kit.  I'll make a version of the STEP/STL with smaller pin diameter.  I'll make the holes to be 2.95mm instead of 3.1mm.  I'll try to send you a version later tonight.

Sorry for all the trouble and thanks for the feedback.

Note: since you are the first one I know to attempt install on the trident, feedback on the need for top bearing support would greatly be appreciated.

thiagolocatelli, 2023-04-12:
@MirageC79 do not be sorry! it is all good.

I converted all 1.55mm radius to 1.45mm radius and am printing right now. The small adapter it worked perfectly. Going to test the Z plates and then the rear Z.

For the rear Z I did this and if it works I can send you the step files

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

thiagolocatelli, 2023-04-13:
@MirageC79 my adjustments worked me for, making the radius 1.45mm. The rear Z kinda worked because with the recess now that allows the bearing ball to sit flush with the pins, we have those two small faces on each end so had to include a nasty brim there. Wont even share picture here because its not pretty but it does work. If you have another solution/suggestion let me.

Exerqtor, 2023-04-14:
I just noticed these issues too and made the exact same changes to my MGN12H version lol, thought I should make an issue about it and saw @thiagolocatelli had allready done so lmao.

Regarding the top bearing support you mention  @MirageC79, are you refering to a potential need for a top support of the leadscrews?

HK-Moebius, 2023-04-15:
I've the issue too.

HK-Moebius, 2023-04-16:
Found a easy workaround for those who not handy with CAD.

Open step file in text editor.
Use find and replace to exchange all 1.55 to 1.45.
Save.
Use Fusion360 or other tool to export step to stl.
Prusa Slicer also can handle step files.

Happy printing :)

thiagolocatelli, 2023-04-17:
@HK-Moebius changing the radius on the step file works for the front plates and adapters but we still need the recessed feature on the rear Z so the metal ball sits flush with the pins and not the printed part.

pila81, 2023-04-25:
In addition to the missing feature mentioned above, the recessed nut hole is missing the bridges allowing for support-free printing:
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

On a side note: my pins are 2.99 mm and found a slot radius of 1.50 mm worked best for me.

Exerqtor, 2023-04-26:
> I just ran into the issue with the lack of a recess in the rear mount and come here to report it. On the other hand, all the pins fit fine on my printed parts.

I just released a fixed[ MGN9H version](https://github.com/Exerqtor/Voron/tree/main/Mods/vt_rear_wobblex_carriers) as well

MirageC79, 2023-04-27:
Sorry guys, been pulled away for past couple of weeks due to personal stuff.  Will be looking at fixing this over the weekend.
Thank you for the input!  and @Exerqtor great work! May I include your parts in this repository?

Cheers!

Exerqtor, 2023-04-27:
> Sorry guys, been pulled away for past couple of weeks due to personal stuff. Will be looking at fixing this over the weekend. Thank you for the input! and @Exerqtor great work! May I include your parts in this repository?
>
> Cheers!

Hope you're doing well!

Yeah ofc, do as you like with them 😊

claudermilk, 2023-04-28:
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

I actually just found your part on Printables. I just posted my make over there--it works great. I now have WobbleX installed with your updated model. No longer does my Trident howl while running down the Z travel--this mod is clearly working.

Exerqtor, 2023-05-01:
I finally got around to print this (and the front ones) myself, and i had to go with Ø 3.0mm for the pins just FYI.

slashbeast, 2024-05-09:
Thanks @Exerqtor, I am using your remix for a few months and it works great for me. Would be great if those in-repo Trident parts would be fixed, because the rear without the channel to roll ball in is just quite literally unusable.

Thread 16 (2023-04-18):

Parts for Sidewinder X1

acheljay, 2023-04-18:
Hi, could it be possible to have parts for the sidewinder X1, certainly one of the most wobbly printer I know ? Many thks in advance

washo4evr, 2023-04-21:
would X1 parts fit the X2?

acheljay, 2023-04-21:
I don't think cause the X2 have a new anti wobble system with spring tension for the wheels

gt3rs40, 2023-04-22:
X1 parts would be awesome

Caos-Maker89, 2023-05-16:
waiting for x1 parts :)

acheljay, 2023-07-25:
yup always interrested cause I did'nt find any good one for the X1

gt3rs40, 2023-07-25:
Still interested :)

washo4evr, 2023-07-26:
can this be ported to the X2? How different are the 2 models?
I just received my wobbleX yesterday but not sure how to install on my X2

fkahhaleh, 2023-07-28:
Alright
So Amazon didn't delivery the parts today as planned. Instead of keeping you guys from potentially trying it out.
Here is a link to [Thingiverse](https://www.thingiverse.com/thing:6144103).

It is heavily a WIP/concept that I have not tried.  Keep that in mind :)

Feedback is welcome of course!

fkahhaleh, 2023-07-29:
Perhaps a quick update on my end.
I was surprised that my Sidewinder X1 (v4) already had a similar mechanism to address Z-banding. (basically a blue cube with the brass nut inside with some degree of freedom for movement)
But I did install one side and I noticed that when there is z-axis movement, the rotation actually gets the Wabble-X moving too much that it actually almost jumps the metal ball bearings. Perhaps this is similar to the weight distribution issue mentioned in the wiki.

I ended up replacing the original parts for the X1 because the above design I provided did not work!

ApolloF, 2023-08-24:
You can just use the mockup parts for the x1.

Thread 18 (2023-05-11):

WobbleX ball size

woodwaker, 2023-05-11:
I ordered 6 WS8kits from the Mellow store and just installed the first set on my Rat Rig 3.1.  During the installation I lost one of the ball bearings, I can not find the specs for them,  could you include the sizes for each kit?  I also left a message for Mellow, it might be a good idea to either include an extra ball or have them as an option.

woodwaker, 2023-05-11:
Thanks for making me feel better, not being the only one that had lost a ball.  I have an assortment on order from Amazon, and will update if I have success.

woodwaker, 2023-05-12:
These are 4mm ball bearings.  I was in a hurry so ordered an assortment from Amazon
https://www.amazon.com/gp/product/B08KTBM74G/ref=ppx_yo_dt_b_asin_title_o00_s00?ie=UTF8&th=1
I would suggest that your order some from AliExpress the same time as you order the WobbleX

MirageC79, 2023-05-18:
Sorry to hear that, yes they are 4mm Steal balls.  I have asked Mellow to put extra in the kits.
Thanks for reporting this.

woodwaker, 2023-05-18:
Thanks for the reply!
I am sure it was my fault, but I could not figure out a good way to get the WobbleX stack installed in each Z axis arm without balls dropping out.
I ordered an assortment that included 50 4mm ball and I think both of my Rat Rigs are now running well.My friend Tim of DWIT3D Canada is going to install on his RatRig in the next week or so, I ordered the same set for him so he will be prepared.I think he will do a live steam of the install.  Here is his channel   ***@***.***/streams
I see a couple of problems, the magnets don't seem to be powerful enough for the stainless steel balls and they are not constrained.
I putting everything back into the Z axis printed part it is easy to slightly move the alignment and the balls find freedom.

dave wilson 816 792 1060

    On Wednesday, May 17, 2023 at 08:58:11 PM CDT, Mirage ***@***.***> wrote:

Sorry to hear that, yes they are 4mm Steal balls. I have asked Mellow to put extra in the kits.
Thanks for reporting this.

—
Reply to this email directly, view it on GitHub, or unsubscribe.
You are receiving this because you authored the thread.Message ID: ***@***.***>

Closed 2023-05-18.

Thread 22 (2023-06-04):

Improve V-Core 3.1 TR8 Adapter Body

HelgeKeck, 2023-06-04:
On the V-Core Bed arms i can push the pins to the end and i know they are in the right position.

It would be nice if it works the same way for the TR8 adapters. There should a stop to make sure the pins are located correctly. If you push the pin to the end, against the pom nut, they are far away from the being centered.

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

Closed 2023-06-11.

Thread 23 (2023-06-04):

V-Core 3.1 Improved Multicolor STLs

HelgeKeck, 2023-06-04:
Not really a issue, more a suggestion.

These arms with the nice logo do scream for a multicolor print. Not everyone uses a slicer that can directly paint onto a object to create multicolor parts.

Multicolor painting on objects creates anyway very weird internal geometries
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

Seperate Arm and Logo parts would be much better i think. resulting in much better multicolor prints that can be used with any slicer
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

Closed 2023-06-11.

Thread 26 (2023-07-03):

Ratrig BOM

kevinkga, 2023-07-03:
The current link to the ws8 variant of wobblex points to a kit that has 8 dowel pins in total. All of these are used by the WobbleX itself.

However, it'd seem like the lower disc adaptor needs additional pins. Could we please have the BOM updated to account for these additional pins? What specs are they and where can they be bought (in the UK)?

ZeyHex, 2023-07-03:
There are 8 pins in addition to those already installed in WobbleX.

kevinkga, 2023-07-03:
Thanks for the clarification! that makes perfect sense. I just wish Mellow would clarify that in the product description/BOM

Closed 2023-07-03.

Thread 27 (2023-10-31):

Ender5 S1 stl

homeveg, 2023-10-31:
Hi,

I would like to install a WobbleX on Ender5 S1, and it needs an adapter with a bigger distance between shrews.
Any chance you can share a CAD model, so one can modify it? Or maybe you already have the model for a Ender5 S1

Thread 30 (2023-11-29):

Generic interface missing?

vuokko, 2023-11-29:
Shouldn't there be a generic interface?

While staring all the moving devices around me, the up-down movement has been made with hole through a plate and the screw goes through it. Then the nut is under the plate. Not the fanciest design but seems to be quite common.

I think the most generic interface would be something where the existing  lead screw nut was used. And the interface would allow attaching similar way to existing hole pattern. So that the nut just drops lower and the wobblex comes between.

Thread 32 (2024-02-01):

Just a question... For Kobra 2 Max

cptcl, 2024-02-01:
Hello... i have an Anycubic Kobra 2 Max and would also like to eliminate ZWobble completly with this mod.

- For this part.."Following user feedback, this system is not recommended for Dual Z cartesian printers. The WobbleX require a certain amount of weight to keep them together. A Dual Z installation would divide the XZ gantry weight."

wouldnt it be possible to mount 2 pieces of the WobbleX on both Z-Axis? so 1 from below, like in your pics and the other one on top, so that u do like a "push pull config" on the Z carrier? Should work.. no? You wou´ld just need a 2nd nut for the 8mm screwrod for the top part..? (also prints adapted to carrier mount for mounting both sides) so u dont have a problem with weight.
Doable? what u guys think?

PS: also an idea for the Ender3

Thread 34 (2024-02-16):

Z Wobble X and Ender 3 v2 Issue

bobster316, 2024-02-16:
I am using the official Z wobble x kit purchased from Aliexpress. The issue I
have can be est described in a video i captured when the issue happens.
[https://youtu.be/8Wd88ihQccs](url)

As the printer homes, the z axis lowers and while lowering near the bed, the z wobble x serperates
and the nozzle hits the bed.

Can you please advise what could be causing the issue.

Thanks

leecuk, 2024-02-17:
Looks like you've got it on upside down.

Compare yours to mine -
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

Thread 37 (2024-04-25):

Z wobble X

bobster316, 2024-04-25:
I have a z wobble x, while re building my machione and ended up losing some of the ball bearings. I ordered some replacements from Amzon. The ball bearings are not being attracted to the magnetic disk on the metal z wobblex part. Can you please provide specific details of the type of ball bearings I should order. Thanks

leecuk, 2024-04-29:
I think if you look for 420 or 440 steel rather than 304 you might have better luck. You can find them on amazon.

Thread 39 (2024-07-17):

Voron Trident top leadscrew support

ManiekJG, 2024-07-17:
Wanted to actually ask one question. On Ratrig and Enders it is required to get a support on top of leadscrew in order for it not to wobble too much. Is it not same case for Voron Trident?

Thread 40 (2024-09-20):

Ender 3 ball jumps the pin

moff3tt, 2024-09-20:
Hello,

I installed the wobblex on my old ender 3 pro and I find that one of the balls tends to jump over the pins and ride the outside of one instead of in the center.

I'm not sure what is causing it. I have installed everything as close to the instructions as possible and my z is so well aligned it will fall on its own with the stepper off.

(Note I had to use a little bit of hot glue to keep the pins in the printed parts since mine came out a tad loose)

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

moff3tt, 2024-09-21:
further analysis of the issue has provided the root cause. When my bl touch fails to probe the whole system goes slack which allows the WobbleX to come loose since it falls a little more than the x gantry then when I reset the printer and the z axis goes back up the ball is misaligned. Any guidance on how to mitigate this issue so manual intervention is not required is appreciated.

leecuk, 2024-10-20:
Maybe the same approach as when using 2 lead screws, some people use bands etc to pull them together, although sounds like your real problem is the bl touch, is it genuine or a clone?, I've only used a clone and it was junk, I've got a genuine creality probe and it works flawlessly.

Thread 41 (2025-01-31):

Formbot Marathon - Interface Plates Pinching/Clapping

phiferch, 2025-01-31:
I recently purchased a Formbot Marathon printer, which has 3 ball screws, with the WobbleX mechanism attached to all three. I noticed that when I lowered the bed, sometimes the interface plates of the WobbleX would sorta bind up and pinch, making this unsettling clapping noise. Is this the same issue as the bed needing to be heavy enough to keep the plates together? Any assistance would be greatly appreciated. Video for reference.

https://www.youtube.com/watch?v=QI-7QPU0SkM

leecuk, 2025-02-02:
I'm not sure it is, I can't actually see any ball bearings between the needle bearings, are they missing?

Did you do the install?

@phiferch

leecuk, 2025-02-04:
Assuming the top plate over the wobblex is attached correctly with no issues, then it might be the cause you suggested.

Does it work ok if you apply downward pressure to the build plate when lowering?

I’m not familiar with the printer, but a quick Google came back with someone on Reddit having separation issues and were using springs to pull the plates together.

https://www.reddit.com/r/FixMyPrint/comments/190a40r/thoughts_on_my_wobblex_adapter/?rdt=42573

Something like rubber o-rings may work, but not sure how it would affect the performance.

You may find the effort isn’t worth the reward, but I don’t know how badly your printer performed beforehand.

My only experience of the wobblex is with the ender3, but it really does work on that.

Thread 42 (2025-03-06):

Rat-Rig Vcore-4

piotrgrundas, 2025-03-06:
Any plans for creating parts for VC4?

If no, is there anywhere cad model for WoobleX so I could play with it myself?

leecuk, 2025-03-11:
@piotrgrundas

Step files available for the 3.1 over at https://github.com/MirageC79/Interfaces-for-WobbleX-integration/tree/main/RatRig/VCore3.1

Might give you a head start or some ideas.

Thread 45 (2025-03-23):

[Creality Ender 3] TR8_Adapter and ZCarriage holes are not properly aligned

igox, 2025-03-23:
- WobbleX_TR8_Adapter Body: holes are 2mm too close.
- ZCarriage_WS8: One of the three holes is not properly aligned with the support.

I proposed a fix in PR #44

This has been physically validated on my own Ender 3:

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

leecuk, 2025-03-23:
@igox

https://github.com/MirageC79/Interfaces-for-WobbleX-integration/issues/7

igox, 2025-03-24:
Closing this issue as a duplicated of #7. But I let open my PR #44 as the files on the main branch are still faulty.

Closed 2025-03-24.

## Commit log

2023-02-18 Voron Trident
    [WobbleX_TR8_Adapter v6.stl, ZCarriageLeft_WobbleXPlate.stl, ZCarriageRight_WobbleXPlate.stl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]
2023-02-22 RatRig V-Core 3.1 Initial Load
    [BedArmBack_3.1_WS8.stl, BedArmLeft_3.1_WS8.stl, BedArmRight_3.1_WS8.stl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]
2023-02-22 Voron Trident Update
    [WobbleX_TR8_Adapter Body.stl, WobbleX_TR8_Adapter v6.stl, ZCarriageLeft_Plate_WS8.stl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]
2023-02-22 Step Files added
    [BedArmBack_3.1_WS8.step, BedArmLeft_3.1_WS8.step, BedArmRight_3.1_WS8.step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]
2023-03-30 Ender3 Added
    [ZCarriage_WS8.step, ZCarriage_WS8.stl]
2023-03-30 Mockups added
    [WobbleX_WS12_MockUp.step, WobbleX_WS12_PrintedAdapter.step, WobbleX_WS16_MockUp.step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]
2023-03-31 Added Ender 5 Plus support
    [TopBearingSupport_608.stl, WobbleX_WS8_Ender5PlusAdapter.step, WobbleX_WS8_Ender5PlusAdapter.stl]
2023-03-31 Refined screw hole spacing
    [WobbleX_WS8_Ender5PlusAdapter.step, WobbleX_WS8_Ender5PlusAdapter.stl]
2023-03-31 added tolerance for spring washer, boltshould sit flush
    [WobbleX_WS8_Ender5PlusAdapter.step, WobbleX_WS8_Ender5PlusAdapter.stl]
2023-03-31 CrealityEnder3 documents added
    [WobbleX_TR8_Adapter Body.step, WobbleX_TR8_Adapter Body.stl]
2023-03-31 Update README.md
    Added note for relocating stock extruder
2023-04-04 Update README.md
    Corrects printer name
2023-04-07 Update WobbleXII_upper.stl
    correction
    [WobbleXII_upper.stl]
2023-04-07 thread added
2023-04-07 .step added
    [WobbleXII_lower.step, WobbleXII_upper.step]
